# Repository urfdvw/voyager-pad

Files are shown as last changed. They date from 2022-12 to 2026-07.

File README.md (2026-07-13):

# Voyager Pad
A CircuitPython based macropad featuring xiao rp2040.
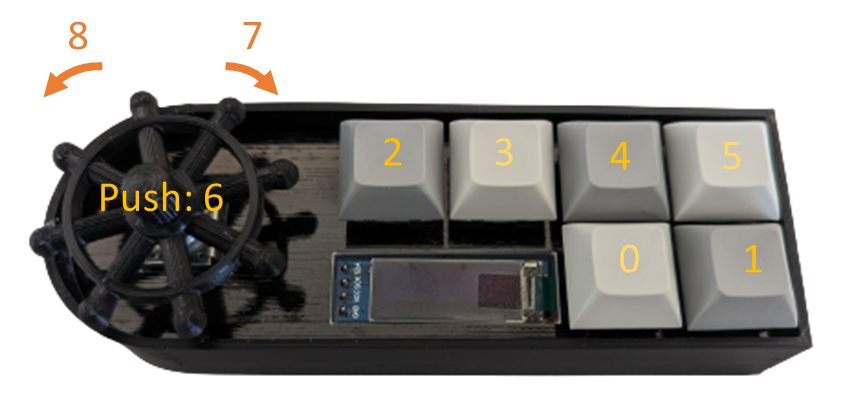
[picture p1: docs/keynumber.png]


## Features
- Code-free macros
    - supports keyboard, mouse, media control macros
    - supports key combinations and sequences
    - supports text typing
- Display hints on the screen
- [Web based settings editor](https://urfdvw.github.io/voyager-pad/)
    - edit macro layers in tabs, add and remove layers
    - macro validation with clear error messages
    - autocompletion of key code names

## Guides
- [How to configure the device to use different macros](./guides/configure.md)
- [Example use cases](https://github.com/urfdvw/voyager-pad/tree/main/example%20settings)
- [How to update the firmware of the device](https://github.com/urfdvw/voyager-pad/releases)
- How to make a Voyager Pad for yourself (coming soon)
- How to use Voyager Pad code on other macropads (comming soon)

## Dependencies
- CircuitPython7.3.3
- adafruit_display_text
- adafruit_hid
- adafruit_displayio_ssd1306.mpy
- adafruit_framebuf.mpy

## Planned Features
- On device profile switch (mid term)

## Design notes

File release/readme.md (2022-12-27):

# Update log

## Voyager Pad firmware release version 1.0.1

How to update firmware:
1. Connect your device with the computer with a USB cable, it should show up as a drive called 'CIRCUITPY'.
2. Download the 'voyager_pad_firmware_x.x.x.zip' file from the list below.
3. Extract all.
4. Copy all file to 'CIRCUITPY' drive. This should replace all existing code but won't affect your macro settings.

What is changed since 1.0.0
- Added `WAIT_MS` macro

## Voyager Pad firmware release version 1.0.0

How to update firmware:
1. Connect your device with the computer with a USB cable, it should show up as a drive called 'CIRCUITPY'.
2. Download the 'voyager_pad_firmware_x.x.x.zip' file from the list below.
3. Extract all.
4. Copy all file to 'CIRCUITPY' drive. This should replace all existing code but won't affect your macro settings.

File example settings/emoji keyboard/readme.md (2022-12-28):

*Please backup your current settings.json before trying this example*

replace the 'settings.json' in 'CIRCUITPY' drive with the one in this folder to try out.

# Emoji Keyboard
This is an Example of how to use complex macros to achieve some goals, such as open system emoji pannel, then search for an emoji and then insert it.

The mac version is way more complex than the Windows version, because mac os has way longer animations. As a result, `WAIT_MS` macro has to be used a lot to wait for the animation finish before the next operation.

##  Reference
emoji names: https://www.makeuseof.com/top-emojis-explained-cheat-sheet/

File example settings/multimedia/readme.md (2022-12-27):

*Please backup your current settings.json before trying this example*

replace the 'settings.json' in 'CIRCUITPY' drive with the one in this folder to try out.

# Multimedia
This is an example of how to use the Voyager Pad for media play back.

## Layers
Layer -1: Example of regular media control
- rotate encoder to change the volume
- 2: Mute
- 3 ~ 5 media playing control
    - 3: previous track
    - 4: play/pause
    - 5: next track

Layer 0: Example of media player shortcuts
- This example is for Quick Time on Mac only
- 4,5: Rewind/Fast Forward
- encoder: navigate through frames.

Layer 1
- rotate encoder to change the screen brightness

other buttons or layers are not enabled

##  Use cases
Online music player examples
- https://soundcloud.com/fm_freemusic.

VLC shortcuts
- https://www.maketecheasier.com/cheatsheet/vlc-keyboard-shortcuts/

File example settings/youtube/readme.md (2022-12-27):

*Please backup your current settings.json before trying this example*

replace the 'settings.json' in 'CIRCUITPY' drive with the one in this folder to try out.

# Youtube controls
This is an use case example.
Medeia control keys and keyboard shortcuts are used.

## Layers
Layer -1: basics
- 2, 7, 8: Volume control
- 3~6: Playback control

Layer 0: time-related
- 2, 3: speed
- 4, 5, 7, 8: seek

Layer 1: screen control
- 2: CC
- 3~5: video size
- 7, 8: screen brightness

##  Use cases
Try out the short cuts on https://www.youtube.com/.

Shortcut reference: https://support.google.com/youtube/answer/7631406?hl=en.

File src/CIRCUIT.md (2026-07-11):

# Circuit / Pin Connections

This document describes the physical wiring expected by `code.py` /
`macropad.py` on the **Seeeduino XIAO RP2040** board (board id
`seeeduino_xiao_rp2040`, see `boot_out.txt`).

The XIAO RP2040 silkscreen labels some pins differently from the
CircuitPython `board.*` names used in this code. The table below gives
both.

## OLED Display (SSD1306, 128x32, I2C)

Driven by `adafruit_displayio_ssd1306` over I2C at address `0x3C`,
1 MHz bus speed (see `code.py`).

| Display pin | Connects to (code) | XIAO silkscreen |
|---|---|---|
| SDA | `board.SDA` | SDA |
| SCL | `board.SCL` | SCL |
| VCC | 3.3V | 3V3 |
| GND | GND | GND |

## Macro keys (7 tactile switches)

Each switch wires one leg to the listed pin and the other leg to GND.
Firmware enables an internal pull-up and treats the key as pressed when
the pin reads low (`pull=True, value_when_pressed=False` in
`MacroKeyPad`), so no external resistors are needed.

| key_number | code pin | XIAO silkscreen | Role (from `macropad.py` / `settings.json`) |
|---|---|---|---|
| 0 | `board.D10` | MOSI | Lower row, key 1 — hold to select layer 0 |
| 1 | `board.D6` | TX | Lower row, key 2 — hold to select layer 1 |
| 2 | `board.D3` | A3 | Upper row, key 1 — macro key |
| 3 | `board.D2` | A2 | Upper row, key 2 — macro key |
| 4 | `board.D1` | A1 | Upper row, key 3 — macro key |
| 5 | `board.D0` | A0 | Upper row, key 4 — macro key |
| 6 | `board.D9` | MISO | Rotary encoder push button ("nob") — macro key |

Note: the "lower row" / "upper row" grouping above comes from the
inline comments in `code.py`; wire the physical rows to match your own
enclosure if it differs.

Layer 0 and layer 1 (key_number 0 and 1) are momentary: holding them
switches to that layer, releasing returns to the default layer (`-1`).
Key numbers 2–6 emit whatever macro is configured in `settings.json`
for the currently active layer.

## Rotary encoder

A quadrature rotary encoder provides scroll/volume-style input, decoded
by `rotaryio.IncrementalEncoder`. Its push button is wired as key 6
above (shared with the macro key matrix, not a separate input).

| Encoder pin | code pin | XIAO silkscreen |
|---|---|---|
| A | `board.D8` | SCK |
| B | `board.D7` | RX |
| Push button | `board.D9` | MISO (see key_number 6 above) |

Rotation does not use extra physical pins beyond A/B: clockwise steps
are reported by software as virtual `key_number 7`, counter-clockwise
steps as virtual `key_number 8` (see `MacroKeyPad.events` in
`macropad.py`). These correspond to the `"7"` and `"8"` macro entries
in `settings.json`.

## USB

The board connects to the host over USB for both power and the
keyboard/mouse/consumer-control HID interface (see `boot.py`).

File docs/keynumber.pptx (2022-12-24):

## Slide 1

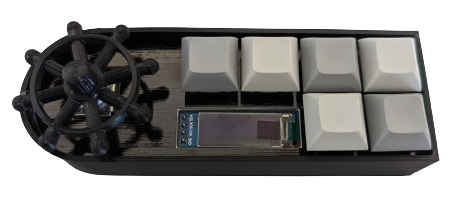
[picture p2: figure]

8

7

Push: 6

2

3

4

5

0

1

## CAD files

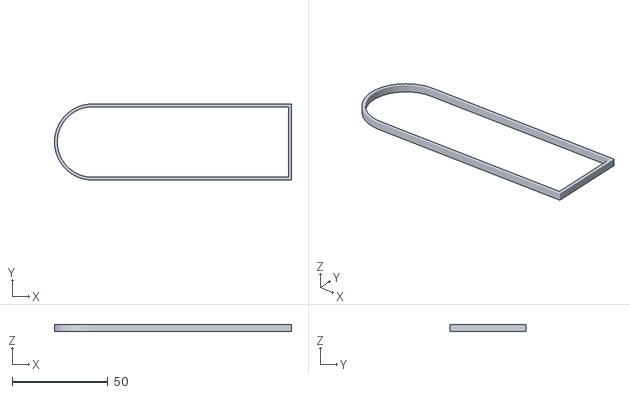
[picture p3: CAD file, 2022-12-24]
3d model/MacroPadFrame.stl
123.5 x 39.6 x 3.40

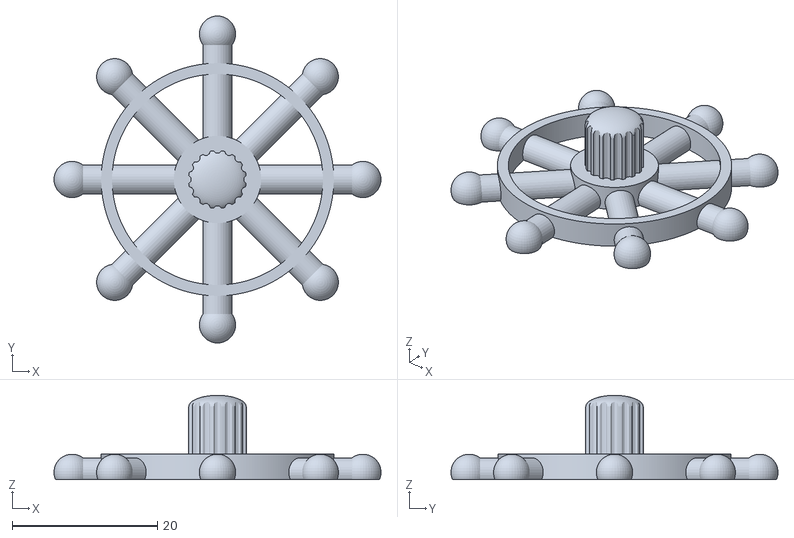
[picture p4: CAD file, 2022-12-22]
3d model/knob.stl
45.0 x 45.0 x 11.6

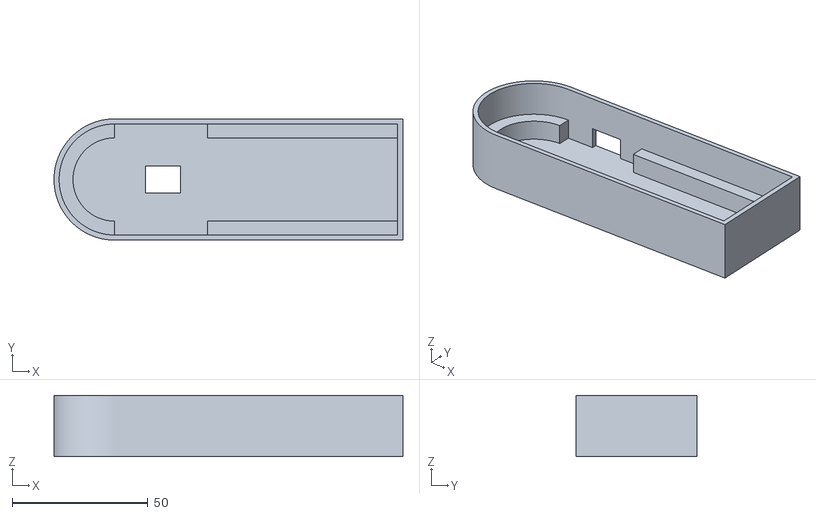
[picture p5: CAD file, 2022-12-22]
3d model/MacroPadCase.stl
128.5 x 44.6 x 22.6

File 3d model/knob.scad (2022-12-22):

$fa = 1;
$fs = 0.4;

err = 0.1;
large_num = 200;

function mm(mil) = mil * 0.0254;
max_r = mm(850);
encoder_height = 7.5;
encoder_dent = 1.5;
encoder_r = 3;
encoder_rim_r = 0.6;
encoder_rim_h = encoder_height / 2;
knob_height = 10;
knob_r = 4;
knob_dent_r = 0.6;
knob_dent_offset = 0.2;
knob_dent_n = 16;
wheel_thickness = 3.5;
plate_r = 6;
frame_outer = 16;
frame_inner = 14.5;
rod_l = 20;
rod_r = 2;
rod_sink = 1;
rod_n = 8;
head_r = 2.5;

module encoder() {
    translate([0, 0, -err]) 
    cylinder(
        h = encoder_rim_h,
        r1 = encoder_r + encoder_rim_r,
        r2 = 0
    );
    difference() {
        translate([0, 0, -large_num + encoder_height]) 
            cylinder(h = large_num, r = encoder_r + err);
        translate([encoder_r - encoder_dent, -large_num / 2, -large_num / 2])
            cube(large_num);
    }
}

module knob(){
    translate([0, 0, knob_height])
    scale([1, 1, 0.4]) 
        sphere(r = knob_r);
    difference() {
        cylinder(h = knob_height, r = knob_r);
    }
}

module nice_knob() {
    difference() {
        knob();
        for ( i = [0 : knob_dent_n-1] ){
            rotate([0, 0, 360 / knob_dent_n * i]) 
            translate([knob_r + knob_dent_offset, 0, -large_num / 2]) 
            cylinder(h = large_num, r = knob_dent_r);
        }
    }
}

module wheel() {
    cylinder(h = wheel_thickness, r = plate_r);

    difference() {
        cylinder(h = wheel_thickness, r = frame_outer);
        translate([0, 0, -large_num / 2]) 
            cylinder(h = large_num, r = frame_inner);
    }

    difference(){
        for ( i = [0 : rod_n-1] ){
            translate([0, 0, rod_r - rod_sink]) 
                rotate([0, 0, 360 / rod_n * i])
                rotate([0, 90, 0]) 
                cylinder(r=rod_r, h=rod_l);
            rotate([0, 0, 360 / rod_n * i])
                translate([rod_l, 0, rod_r - rod_sink]) 
                sphere(r=head_r);
        }
        translate([-large_num / 2, -large_num / 2, -large_num]) 
        cube(large_num);
    }
}

difference() {
    union() {
        wheel();
        nice_knob();
    }
    encoder();
}

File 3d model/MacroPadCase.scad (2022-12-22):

$fa = 1;
$fs = 0.4;

function mm(mil) = mil * 0.0254;
board_r = mm(800);
board_l = mm(4100);
board_thickness = 1.6;
cap_raise = 11;
port_center_x = mm(1400 - 700);
port_height = 8;
port_width = 13;
support_width = 5;
support_l = 70;
case_thickness = 2;

print_err = 0.1;
err = 0.01;
large_num = 200;

module case_outter() {
    outer_height = case_thickness 
                + port_height 
                + board_thickness
                + cap_raise;
    outer_r = board_r + case_thickness;
    outer_l = board_l + case_thickness;
    cylinder(
        h = outer_height, 
        r = outer_r
    );
    translate([0, -outer_r, 0])
        cube([outer_l, outer_r*2, outer_height]);
}

module case_inner() {
    inner_height = port_height 
                 + board_thickness
                 + cap_raise
                 + err;
    translate([0, 0, case_thickness])
        cylinder(
            h = inner_height, 
            r = board_r + print_err
        );
    translate([0, -(board_r + print_err), case_thickness])
        cube([board_l, (board_r + print_err) * 2, inner_height]);
    
}

module port() {
    translate([
        - 0.5 * port_width + port_center_x,
        0,
        case_thickness
    ])
        cube([port_width, large_num, port_height]);
}

module port_bottom() {
    translate([port_center_x, 0, 0])
        cube([13, 10, large_num], center=true);
}

module round_support() {
    difference() {
        cylinder(
            h = port_height + board_thickness, 
            r = board_r + err + print_err
        );
        translate([0, 0, -large_num / 2])
            cylinder(
                h = large_num, 
                r = board_r - support_width
            );
        translate([0, -large_num / 2, 0])
            cube(large_num);
    }
}

module bar_support() {
    difference() {
        translate([board_l - support_l + err, -(board_r + err + print_err) ,0])
            cube([support_l, (board_r + err + print_err) * 2, port_height + board_thickness]);
        translate([0, -(board_r - support_width), 0])
            cube([large_num, (board_r - support_width) * 2, large_num]);
    }
}

// main
difference(){
    union() {
        difference() {
            case_outter();
            case_inner();
        }
        round_support();
        bar_support();
    }
    port();
    port_bottom();
}

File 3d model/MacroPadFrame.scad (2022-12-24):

$fa = 1;
$fs = 0.4;

function mm(mil) = mil * 0.0254;
board_r = mm(800);
board_l = mm(4100);
board_thickness = 1.6;
print_err = 0.5;
plate_raise = 5;
large_num = 200;

frame_height = plate_raise - board_thickness;
frame_thick = 1.5;
frame_r = board_r - print_err;
frame_l = board_l - print_err;

module frame_outter() {
    cylinder(
        h = frame_height, 
        r = frame_r
    );
    translate([0, -frame_r, 0])
        cube([frame_l, frame_r*2, frame_height]);
}

module frame_inner() {
    translate([0, 0, - 0.5 * large_num])
        cylinder(
            h = large_num, 
            r = frame_r - frame_thick
        );
    translate([0, -(frame_r - frame_thick), - 0.5 * large_num])
        cube([frame_l - frame_thick, (frame_r - frame_thick)*2, large_num]);
}

// main
difference () {
    frame_outter();
    frame_inner();
}

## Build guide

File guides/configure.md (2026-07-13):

# Configure

## How to configure the macros on the device
1. Connect the Voyager Pad to computer by USB cable. It will show up as a drive called 'CIRCUITPY'.
2. Open [this page](https://urfdvw.github.io/voyager-pad/): https://urfdvw.github.io/voyager-pad/ in Chrome or Edge.
    - Or open 'Set Macro.url' on the 'CIRCUITPY' drive.
3. In the opened web page, click on 'Open CIRCUITPY folder' and pick the 'CIRCUITPY' drive.
    - If the folder has no 'settings.json' yet, a blank valid one is created automatically.
4. Pick a layer tab, then change the names and macros of the keys.
    - While typing a macro, matching key codes show up under the field: move with the Up/Down arrows, insert with Enter or Tab, dismiss with Escape.
    - An invalid macro is outlined in red; hover over the field to see the reason.
5. Click on 'Save' (or press Ctrl/Cmd+S) to save changes to the device.
    - Saving is blocked while any macro on any layer is invalid.

## Layers
- The default layer `-1` is always there; every other layer is used by holding its layer key.
- Any of keys 0-5 can be a layer key; the knob events (6, 7, 8) cannot.
- Use '+ Add layer' in the web page to create a layer on an unused key, and 'Remove this layer' to delete the selected one (the default layer cannot be removed).
- A layer key cannot carry macros of its own, so adding a layer removes that key's macros from every layer, and removing a layer makes its key assignable again.
 
## Macro terminologies and gramma
- key: a key stroke
- hotkey: a combination of keys to be send together
    - `|` is used to combine keys in the hotkeys
- macro: a set of hotkeys to be send in a sequence
    - `~` is used to combine hotkeys in the macro
- string: a string to be typed out as-is (US keyboard)
    - `''` are used to indicate strings
    - a string is considered as special hotkey

## Supported macro keys
### Keyboard keys
A, B, C, D, E, F, G, H, I, J, K, L, M, N, O, P, Q, R, S, T, U, V, W, X, Y, Z, ONE, TWO, THREE, FOUR, FIVE, SIX, SEVEN, EIGHT, NINE, ZERO, ENTER, RETURN, ESCAPE, BACKSPACE, TAB, SPACEBAR, SPACE, MINUS, EQUALS, LEFT_BRACKET, RIGHT_BRACKET, BACKSLASH, POUND, SEMICOLON, QUOTE, GRAVE_ACCENT, COMMA, PERIOD, FORWARD_SLASH, CAPS_LOCK, F1, F2, F3, F4, F5, F6, F7, F8, F9, F10, F11, F12, PRINT_SCREEN, SCROLL_LOCK, PAUSE, INSERT, HOME, PAGE_UP, DELETE, END, PAGE_DOWN, RIGHT_ARROW, LEFT_ARROW, DOWN_ARROW, UP_ARROW, KEYPAD_NUMLOCK, KEYPAD_FORWARD_SLASH, KEYPAD_ASTERISK, KEYPAD_MINUS, KEYPAD_PLUS, KEYPAD_ENTER, KEYPAD_ONE, KEYPAD_TWO, KEYPAD_THREE, KEYPAD_FOUR, KEYPAD_FIVE, KEYPAD_SIX, KEYPAD_SEVEN, KEYPAD_EIGHT, KEYPAD_NINE, KEYPAD_ZERO, KEYPAD_PERIOD, KEYPAD_BACKSLASH, APPLICATION, POWER, KEYPAD_EQUALS, F13, F14, F15, F16, F17, F18, F19, F20, F21, F22, F23, F24, LEFT_CONTROL, CONTROL, LEFT_SHIFT, SHIFT, LEFT_ALT, ALT, OPTION, LEFT_GUI, GUI, WINDOWS, COMMAND, RIGHT_CONTROL, RIGHT_SHIFT, RIGHT_ALT, RIGHT_GUI
### Media control keys
RECORD, FAST_FORWARD, REWIND, SCAN_NEXT_TRACK, SCAN_PREVIOUS_TRACK, STOP, EJECT, PLAY_PAUSE, MUTE, VOLUME_DECREMENT, VOLUME_INCREMENT, BRIGHTNESS_DECREMENT, BRIGHTNESS_INCREMENT
### Mouse
RIGHT_BUTTON, LEFT_BUTTON, MIDDLE_BUTTON

MOUSE_MOVE_X_Y_W (*Replace `X`, `Y` and `W` with integers representing the move of x-axis, y-axis and scroll wheel*)
### Special (No USB action related)
WAIT_MS (
    since firmware v1.0.1 
    *REPLACE `MS` with an integer reperesenting how many milliseconds to wait*
)

## Macro Examples
- `ALT`: use the key as alt key
- `CONTROL|V`: send Ctrl and V key at the same time
- `CONTROL|A~CONTROL|C`: send Ctrl and A together and then send Ctrl and C together
- `'Hello, World!'`: Type the string out as-is
- `SHIFT|MOUSE_MOVE_0_0_3`: Hold shift and scroll up(down depends on your system) by 3 lines, no cursor move.

see the source code for detailed ['settings.json' examples](https://github.com/urfdvw/voyager-pad/tree/main/example%20settings)

## Raw setting format
All macro configurations are in file `settings.json` with format
```json
{
    "KEY_NUMBER_OF_LAYER_KEY": {
        "KEY_NUMBER": [
            "SHORT_DESCRIPTION", 
            "MACRO"
        ],
        ...
    },
    ...
}
```

Note:
- The default layer number is `-1`, which is not associated with any key number.
- Any of keys 0-5 can be used as layer modifier; knob events (6, 7, 8) cannot.
- SHORT_DESCRIPTION are displayed on the OLED.
- If there is no description or macro, use `""` as space holder.

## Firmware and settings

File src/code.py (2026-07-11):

from time import monotonic
import board
import busio
import usb_hid
import usb_video
import configure
import displayio
import i2cdisplaybus
import adafruit_displayio_ssd1306

from macropad import MacroKeyPad, MONO_128x32, MacroPad, MultiDisplay, USBVideoMirror

# define display
displayio.release_displays()
print('\n' * 10 + 'Hello!')
i2c = busio.I2C(board.SCL, board.SDA, frequency=int(1e6))
display_bus = i2cdisplaybus.I2CDisplayBus(i2c, device_address=0x3C)
display = adafruit_displayio_ssd1306.SSD1306(display_bus, width=128, height=32)
oled_macropaddisp = MONO_128x32(configure, display)
# Mirror the OLED content to a USB video (UVC) framebuffer, so the host
# computer can view it as a webcam feed. The framebuffer itself is sized
# and enabled in boot.py (usb_video.enable_framebuffer). Note: this board's
# CircuitPython build only supports a single displayio Display at a time,
# so the USB video side is driven manually (see USBVideoMirror) instead of
# a second framebufferio.FramebufferDisplay.
usb_macropaddisp = USBVideoMirror(configure, usb_video.USBFramebuffer())
macropaddisp = MultiDisplay([oled_macropaddisp, usb_macropaddisp])
# define keypad
macrokeypad = MacroKeyPad(
    key_pins=(
        board.D10, # lower row
        board.D6,
        board.D3, # upper row
        board.D2,
        board.D1,
        board.D0,
        board.D9, # nob
    ),
    encoder_pins=(
        board.D8, # A
        board.D7, # B
    )
)
# hid
while True:
    try:
        macropaddisp.show_layer_text('USB connecting')
        hid = usb_hid
        macropaddisp.show_layer(-1)
        break
    except Exception as e:
        print(e)
        pass
# define macropad
macropad = MacroPad(
    macrokeypad=macrokeypad,
    configure=configure,
    hid=hid,
    macropaddisp=macropaddisp,
)

while True:
    try:
        macropad()
    except Exception as e:
        print(e)
        macropaddisp.show_layer_text(str(e))
        start = monotonic()
        # display the message for 5 seconds
        while monotonic() - start < 5:
            pass
        # back to macropad program
        macropaddisp.show_layer(-1)

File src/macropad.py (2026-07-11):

# python native
from time import monotonic, sleep
# hardware libs
import rotaryio
import keypad
# display libs
import displayio
from terminalio import FONT
from adafruit_display_text.label import Label
from adafruit_display_text import wrap_text_to_lines
# hid libs
from adafruit_hid.keyboard_layout_us import KeyboardLayoutUS
from adafruit_hid.keyboard import Keyboard
from adafruit_hid.keycode import Keycode
from adafruit_hid.consumer_control import ConsumerControl
from adafruit_hid.consumer_control_code import ConsumerControlCode
from adafruit_hid.mouse import Mouse

class EventQueue:
    def __init__(self):
        self.data = []

    def append(self, given):
        self.data.append(given)

    def get(self):
        if self.data:
            return self.data.pop(0)
        else:
            return None

    def clear(self):
        self.data = []

    def __len__(self):
        return len(self.data)

    def __bool__(self):
        return bool(self.data)


class MacroKeyPad:
    def __init__(self, key_pins, encoder_pins):
        # hardware
        self.encoder=rotaryio.IncrementalEncoder(*encoder_pins)
        self.keys = keypad.Keys(
            key_pins,
            pull=True,
            value_when_pressed=False
        )
        self.n_keys = len(key_pins)
        # queue
        self._events = EventQueue()

    @property
    def events(self):
        position = self.encoder.position
        if position != 0:
            key_number = self.n_keys if position > 0 else self.n_keys + 1
            position = abs(position)
            for i in range(position):
                self._events.append(
                    keypad.Event(
                        key_number=key_number,
                        pressed=True,
                    )
                )
                self._events.append(
                    keypad.Event(
                        key_number=key_number,
                        pressed=False,
                    )
                )
            self.encoder.position = 0

        while event := self.keys.events.get():
            self._events.append(event)
        return self._events



# Shared layout constants + text-building helper, used by BOTH display
# renderers below (the OLED's MONO_128x32 and the USB video mirror
# USBVideoMirror) so the two stay visually in sync and the per-layer
# text-wrapping logic isn't duplicated between them.
LAYER_TEXT_Y = 5
MACRO_TEXT_Y = 15
MACRO_TEXT_SCALE = 2


def build_layer_text(configure_data, width_px=128, char_width=6):
    """Build the per-layer wrapped summary text (e.g. '2:Mute 3:Prev ...')
    shown on both displays, from a configure module's `.configure` dict."""
    return {
        layer: '\n'.join(wrap_text_to_lines(
            ' '.join([
                str(key_number) + ':' + configure_data[layer][key_number][0]
                for key_number in sorted(configure_data[layer].keys())
                if configure_data[layer][key_number][0]
            ])
        , width_px // char_width)
        )
        for layer in configure_data
    }


class MacroPadDisplay:
    def __init__(self, display):
        self.display = display
        self.splash = displayio.Group()
        self.display.root_group = self.splash

        self.layer_group = displayio.Group()
        self.splash.append(self.layer_group)
        self.layer_group.hidden = False
        self.layer_lable = Label(
            FONT,
            text='',
        )
        self.layer_group.append(self.layer_lable)

        self.macro_group = displayio.Group()
        self.splash.append(self.macro_group)
        self.macro_group.hidden = True
        self.macro_lable = Label(
            FONT,
            text='',
            scale=MACRO_TEXT_SCALE,
        )
        self.macro_group.append(self.macro_lable)

        self.layer = -1
        self.state = 0

    def show_layer_text(self, text):
        if (self.layer_lable.text == text
        and self.state == 0):
            return
        self.state = 0
        self.layer_lable.text = text
        self.layer_group.hidden = False
        self.macro_group.hidden = True

    def show_macro_text(self, text):
        if (self.macro_lable.text == text
        and self.state == 1):
            return
        self.state = 1
        self.macro_lable.text = text
        self.layer_group.hidden = True
        self.macro_group.hidden = False


class MONO_128x32(MacroPadDisplay):
    def __init__(self, configure, display):
        super().__init__(display)
        self.configure = configure.configure
        self.layer_text = build_layer_text(self.configure)
        # print(self.layer_text)

        self.layer_lable.color=0xFFFFFF
        self.layer_lable.background_color=0x000000
        self.layer_lable.x=0
        self.layer_lable.y=LAYER_TEXT_Y
        self.layer_lable.line_spacing=0.8

        self.macro_lable.color=0xFFFFFF
        self.macro_lable.background_color=0x000000
        self.macro_lable.x=0
        self.macro_lable.y=MACRO_TEXT_Y
        
        self.show_layer(-1)

    def show_layer(self, layer):
        self.layer = layer
        text = self.layer_text[layer]
        self.show_layer_text(text)

    def show_macro(self, key_number):
        text = self.configure[self.layer][key_number][0]
        self.show_macro_text(text)
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

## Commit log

2022-12-20 3D model
    [MacroPadCase.scad, MacroPadCase.stl]
2022-12-20 update parameters
    [MacroPadCase.scad, MacroPadCase.stl]
2022-12-21 remove clip
    [MacroPadCase.scad, MacroPadCase.stl]
2022-12-21 clean up code, add frame 3d model
    [MacroPadCase.scad, MacroPadCase.stl, MacroPadFrame.scad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]
2022-12-21 change frame fit
    [MacroPadFrame.scad, MacroPadFrame.stl]
2022-12-22 fix a gap
    [MacroPadCase.scad, MacroPadCase.stl]
2022-12-22 3d printed knob
    [knob.scad, knob.stl]
2022-12-22 added rim to encoder
    [knob.scad, knob.stl]
2022-12-23 add error reporting when bad macro
    [code.py, configure.py, macropad.py]
2022-12-24 hid order to fix mouse on mac
    https://github.com/adafruit/circuitpython/pull/4558
    [boot.py]
2022-12-24 fix frame
    [MacroPadFrame.scad, MacroPadFrame.stl]
